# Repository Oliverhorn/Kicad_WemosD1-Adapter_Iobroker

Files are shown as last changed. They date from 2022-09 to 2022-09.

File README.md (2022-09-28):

# Kicad_WemosD1 Adapter_Iobroker
 
Bildschirmfoto 2022-09-13 um 13 02 39
Bildschirmfoto 2022-09-13 um 13 01 05

TO DO für Revision 2:

 1. DSS18B20_GPIO (J1.Pin9) muss noch mit D2(GPIO4) am WEMOS D1 verbunden werden (Leitung fehlt.)
 2. J1 ersetzen gegen JST Buchse, o.ä.. Pinheader sind ungeeignet. Leitungen ziehen sich selbst wieder von Pinheader herunter. Keine Verriegelung!
 3. Outline anpassen an Gehäuse

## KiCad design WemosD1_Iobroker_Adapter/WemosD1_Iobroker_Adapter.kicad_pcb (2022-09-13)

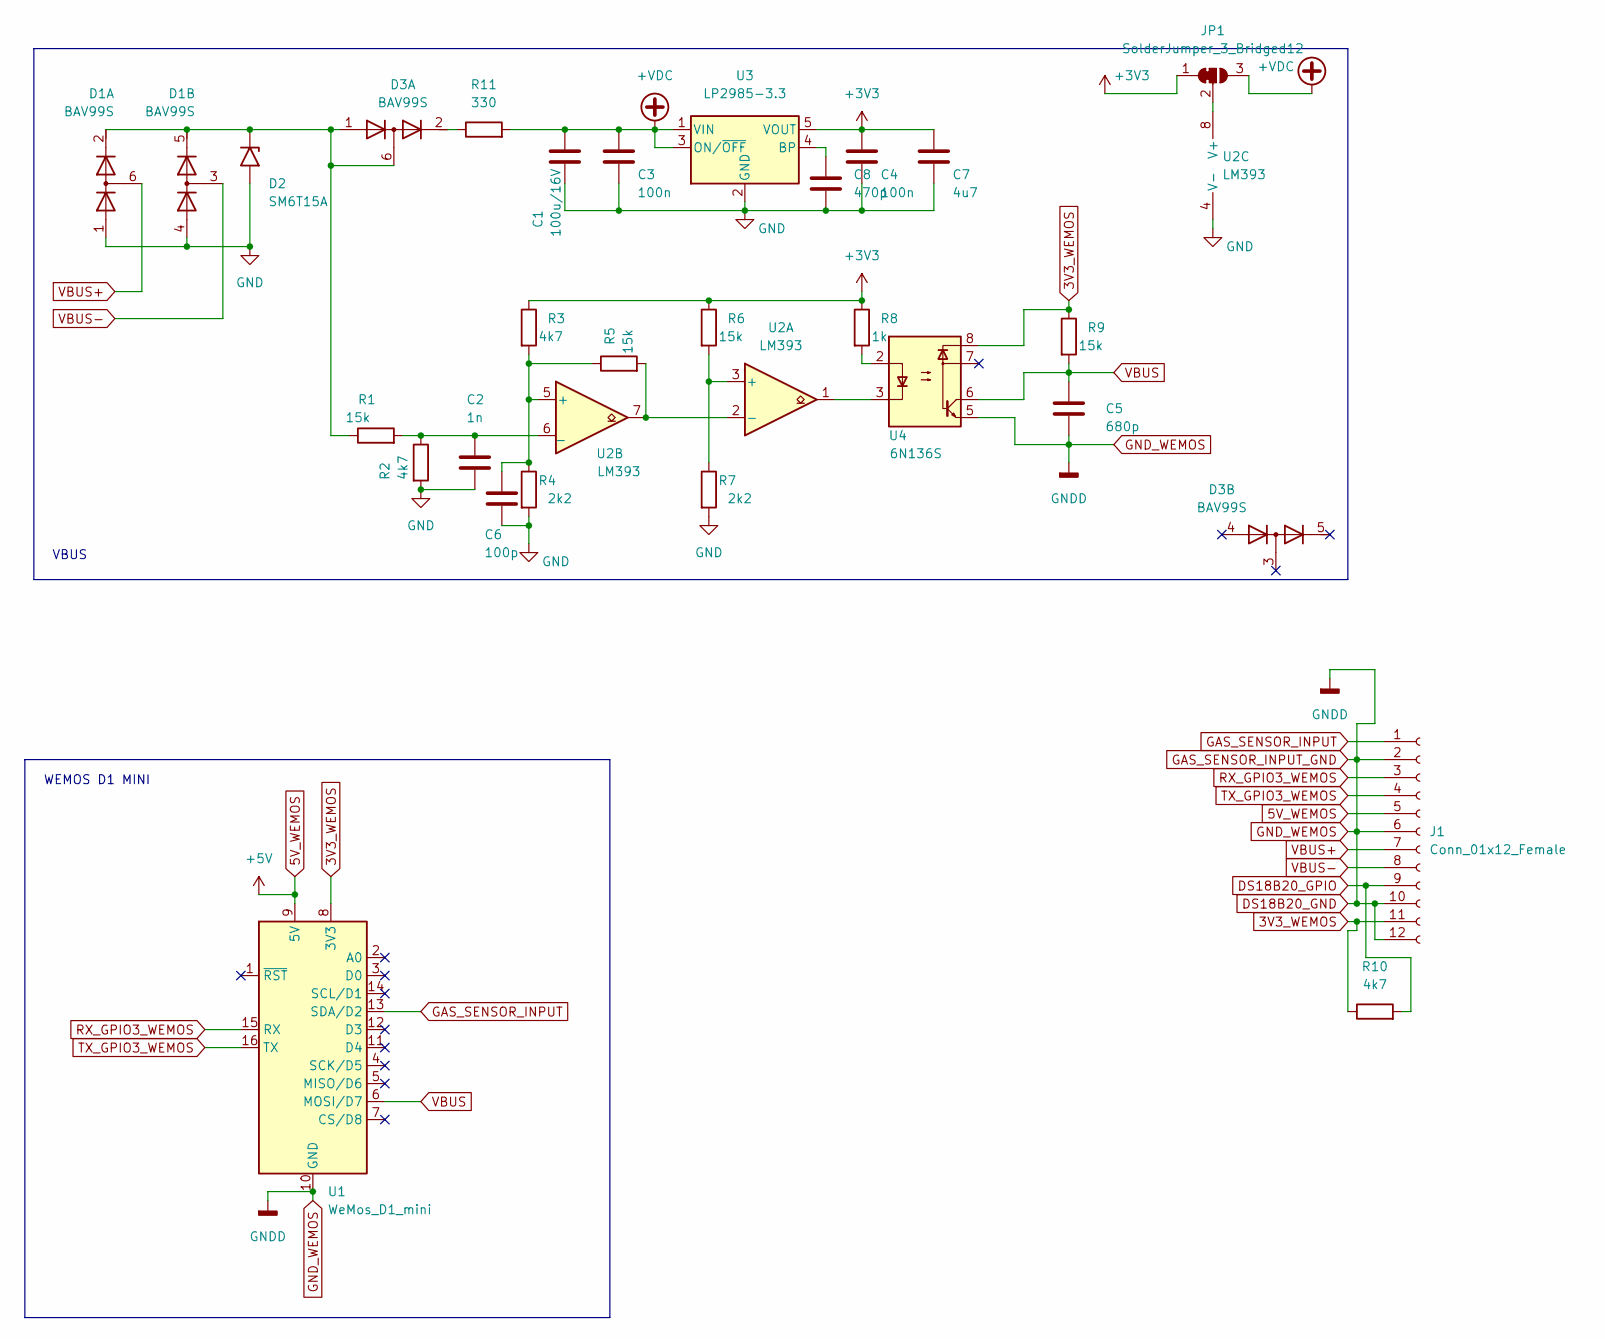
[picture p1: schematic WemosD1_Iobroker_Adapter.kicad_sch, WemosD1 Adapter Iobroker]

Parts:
C1: 100u/16V; CP_Elec_6.3x5.4_Nichicon; LCSC Part # C111600
C2: 1n; C_0402_1005Metric; LCSC Part # C1523
C3, C4: 100n; C_0402_1005Metric; LCSC Part # C307331
C5: 680p; C_0603_1608Metric; LCSC Part # C1630
C6: 100p; C_0402_1005Metric; LCSC Part # C1546
C7: 4u7; C_0402_1005Metric; LCSC Part # C307331
C8: 470p; C_0402_1005Metric; LCSC Part # C1537
D1, D3: BAV99S; SOT-363_SC-70-6; LCSC Part # C68987
D2: SM6T15A; D_SMB; LCSC Part # C1974359
J1: Conn_01x12_Female; PinHeader_2x06_P2.54mm_Horizontal; LCSC Part # C492434
JP1: SolderJumper_3_Bridged12; SolderJumper-3_P1.3mm_Bridged12_RoundedPad1.0x1.5mm_NumberL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
R1, R5, R6, R9: 15k; R_0402_1005Metric; LCSC Part # C25756
R2, R3: 4k7; R_0402_1005Metric; LCSC Part # C25900
R4, R7: 2k2; R_0402_1005Metric; LCSC Part # C25879
R8: 1k; R_0402_1005Metric; LCSC Part # C11702
R10: 4k7; R_0402_1005Metric; MPN C25900
R11: 330; R_0402_1005Metric; LCSC Part # C25104
U1: WeMos_D1_mini; WEMOS_D1_mini_light
U2: LM393; SOIC-8_3.9x4.9mm_P1.27mm; LCSC Part # C7955
U3: LP2985-3.3; SOT-23-5; LCSC Part # C95414
U4: 6N136S; SMDIP-8_W9.53mm; LCSC Part # C118756

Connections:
3V3_WEMOS: J1.11, R9.1, R10.1, U1.8 (3V3), U4.8
5V_WEMOS: J1.5, U1.9 (5V)
+3V3: C4.1, C7.1, JP1.1 (A), R3.1, R6.1, R8.1, U3.5 (VOUT)
+VDC: C1.1, C3.1, JP1.3 (B), R11.2, U3.1 (VIN), U3.3 (ON/~OFF)
DS18B20_GND: C5.2, J1.2, J1.6, J1.10, J1.12, U1.10 (GND), U4.5
DS18B20_GPIO: J1.9, R10.2
GAS_SENSOR_INPUT: J1.1, U1.13 (SDA/D2)
GND: C1.2, C2.2, C3.2, C4.2, C6.2, C7.2, C8.2, D1.1 (A1), D1.4 (A3), D2.2 (A2), R2.2, R4.2, R7.2, U2.4 (V-), U3.2 (GND)
unnamed: C2.1, R1.2, R2.1, U2.6 (_)
unnamed: C6.1, R3.2, R4.1, R5.1, U2.5 (+)
unnamed: C8.1, U3.4 (BP)
unnamed: D1.2 (K2), D1.5 (K4), D2.1 (A1), D3.1 (A1), D3.6 (K3A4), R1.1
unnamed: D3.2 (K2), R11.1
unnamed: JP1.2 (C), U2.8 (V+)
unnamed: R5.2, U2.2 (-), U2.7
unnamed: R6.2, R7.1, U2.3 (+)
unnamed: R8.2, U4.2
unnamed: U2.1, U4.3
RX_GPIO3_WEMOS: J1.3, U1.15 (RX)
TX_GPIO3_WEMOS: J1.4, U1.16 (TX)
VBUS: C5.1, R9.2, U1.6 (MOSI/D7), U4.6
VBUS+: D1.6 (K3A4), J1.7
VBUS-: D1.3 (K1A2), J1.8

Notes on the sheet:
VBUS
WEMOS D1 MINI

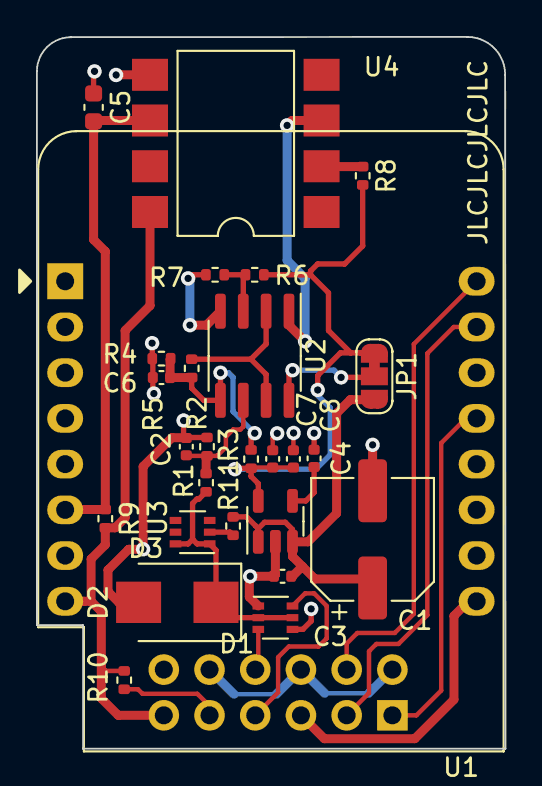
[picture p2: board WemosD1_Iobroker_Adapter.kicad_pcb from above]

Board: 2 copper layers, 26.0 x 39.5 mm, 28 parts (1 on the bottom side), 23 nets.
